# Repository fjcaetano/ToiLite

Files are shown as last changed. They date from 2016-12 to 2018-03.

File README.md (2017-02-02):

ToiLite
=====

A night light that lights up your toilette when you enter your restroom. Inspired by [IllumiBowl](https://illumibowl.com/).

### Partlist:
- 1 ATTiny85
- 1 RGB LED
- 1 LDR Sensor
- 1 PIR Sensor
- 1 Push button
- 1 Timpot (10k)
- 2 100R Resistor
- 2 150R Resistor
- 2 N-Type Mosfet (2N7000)
- 1 L78L33 Voltage Regulator
- 1 0.1µ Capacitor
- 1 0.33µ Capacitor

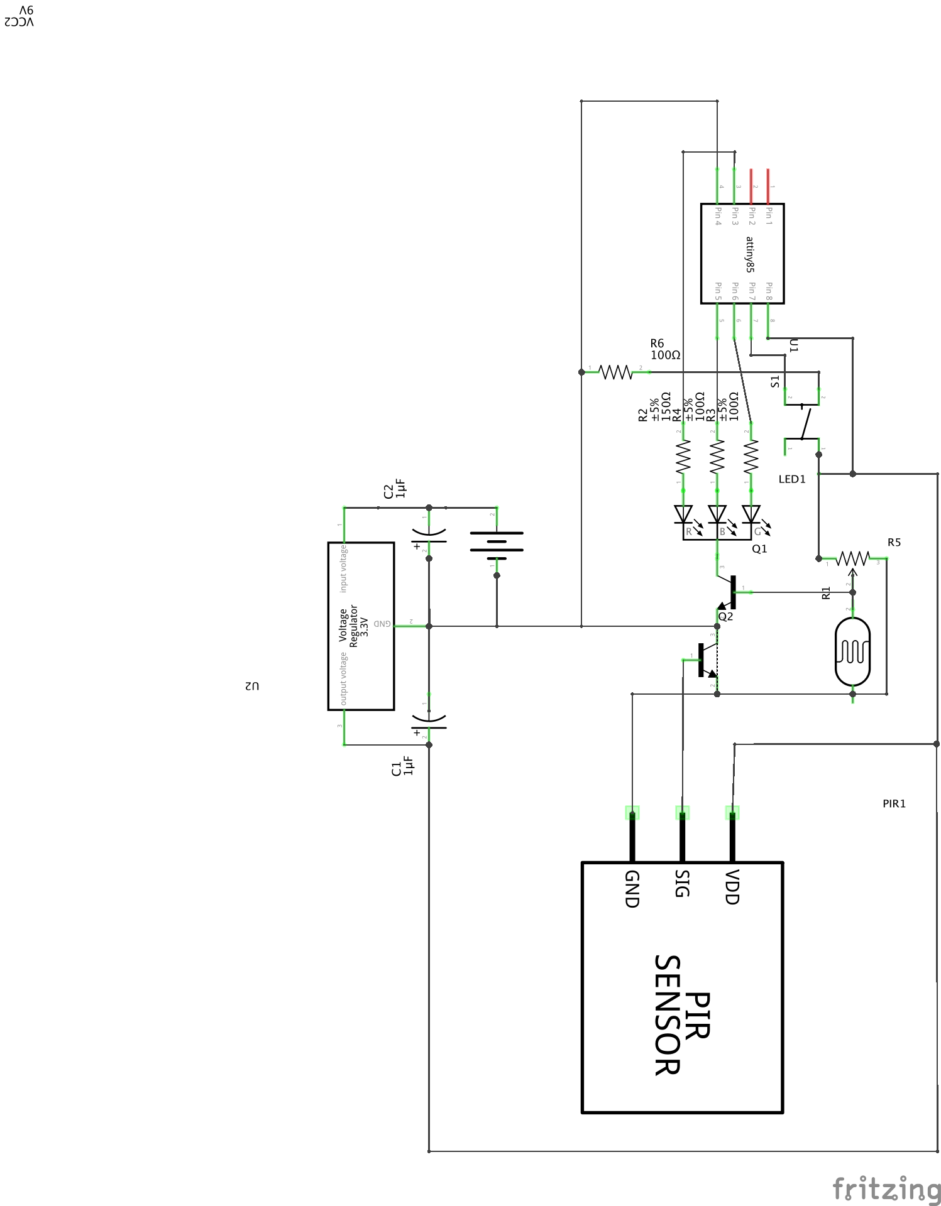
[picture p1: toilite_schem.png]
Schematics


The schematics and prototyping are using an ATTiny85 as microcontroller for the final product, but it can be easily exchanged for an Arduino board for tests.

### Perfboard

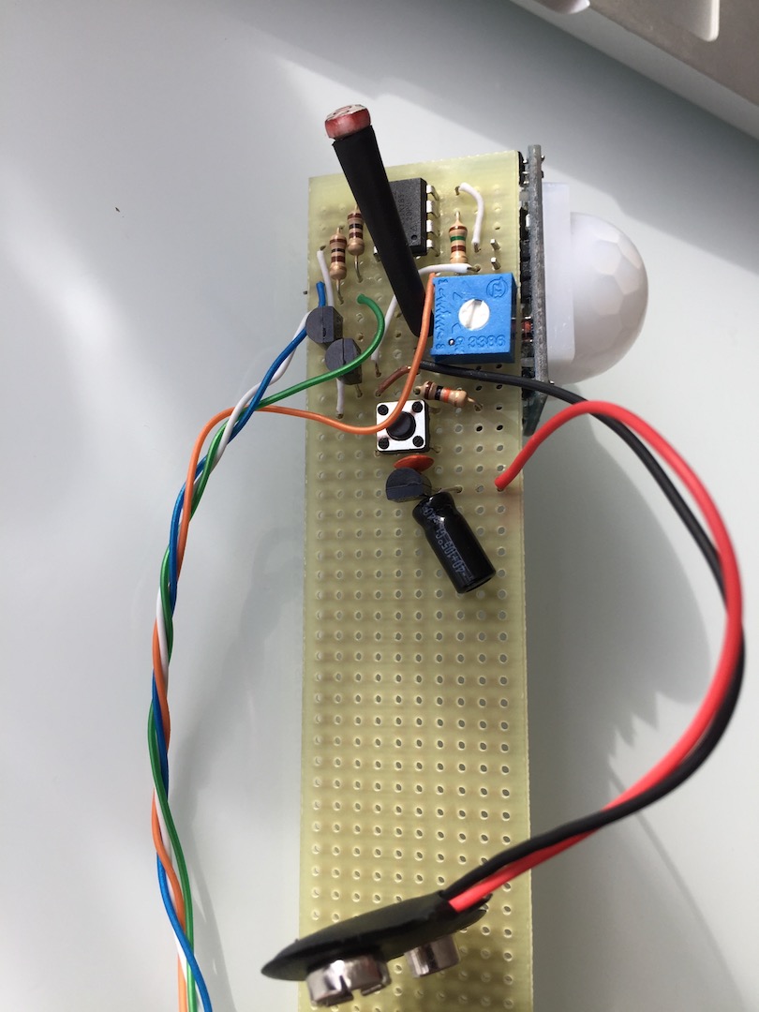
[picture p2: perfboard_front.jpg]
Perfboard front

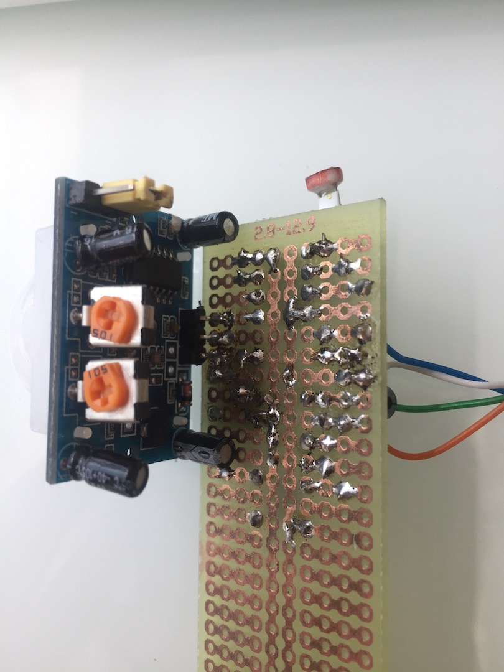
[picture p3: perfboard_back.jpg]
Perfboard back


### TODO
- [x] Hook up the PIR
- [x] Wire it up in a perfboard
- [x] Power source
- [ ] Make a housing for the product
- [ ] Install on a toilette

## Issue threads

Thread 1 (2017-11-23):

Spending too much battery

fjcaetano, 2017-11-23:
The processor doesn't need to be on until the PIR triggers it.

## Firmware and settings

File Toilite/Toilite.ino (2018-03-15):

/*
  ToiLite Controller

  Author: Flavio Caetano
*/

#include <EEPROM.h>

#define RED_PIN PB4 // PIN 3
#define GREEN_PIN PB1 // PIN 6
#define BLUE_PIN PB0 // PIN 5

#define BUTTON PB2 // PIN 7

typedef struct RGB {
  byte r;
  byte g;
  byte b;
};

RGB rgb(int h);
void setColorFromAngle(int angle);
void button_pressed();
void loop_colors(int startAngle);

int currentAngle;
volatile bool shouldStopLooping = false;

int main(void) {
  init();
  initVariant();

  pinMode(RED_PIN, OUTPUT);
  pinMode(GREEN_PIN, OUTPUT);
  pinMode(BLUE_PIN, OUTPUT);

  pinMode(BUTTON, INPUT_PULLUP);
  pinMode(A3, INPUT);

  randomSeed(analogRead(A3));

  // FOR ATTINY85
  GIMSK |= (1 << PCIE);    // turns on pin change interrupts
  PCMSK |= (1 << PCINT2);    // turn on interrupts on pins PB2
  sei();                 // enables interrupts

  int addr0 = EEPROM.read(0);
  int addr1 = EEPROM.read(1);

  currentAngle = (addr0 + (addr1 << 8));

  if (currentAngle != 0) {
    setColorFromAngle(currentAngle);
    shouldStopLooping = true;
  }
  else {
    currentAngle = random(360);
  }

  while (true) {
    loop_colors(currentAngle);
  }
}

ISR(PCINT0_vect) {
  if (digitalRead(BUTTON) == HIGH) return;
  
  if (EEPROM.read(0) == 0) {
    EEPROM.write(0, currentAngle % 256);
    EEPROM.write(1, currentAngle >> 8);

    shouldStopLooping = true;
  }
  else {
    // Clears EEPROM
    EEPROM.write(0, 0);
    EEPROM.write(1, 0);

    shouldStopLooping = false;
  }
}

void loop_colors(int startAngle) {
  for (currentAngle = startAngle; currentAngle < 360; currentAngle++) {
    if (shouldStopLooping) {
      return;
    }

    setColorFromAngle(currentAngle);

    delay(100);
  }

  currentAngle = 0;
}

void setColorFromAngle(int angle)
{
  RGB color = rgb(angle);
  analogWrite(RED_PIN, color.r);
  analogWrite(GREEN_PIN, color.g);
  analogWrite(BLUE_PIN, color.b);
}


RGB rgb(int h)
{
  int angle = (h >= 360 ? 0 : h);
  float sector = float(angle) / 60; // Sector
  int i = floor(sector);
  float f = sector - i; // Factorial part of h

  float q = (1 - f);

  switch (i) {
    case 0:
      return {0xff, int(f * 0xff), 0};

    case 1:
      return {int(q * 0xff), 0xff, 0};

    case 2:
      return {0, 0xff, int(f * 0xff)};

    case 3:
      return {0, int(q * 0xff), 0xff};

    case 4:
      return {int(f * 0xff), 0, 0xff};

    default:
      return {0xff, 0, int(q * 0xff)};
  }
}

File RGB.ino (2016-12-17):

/*
Adafruit Arduino - Lesson 3. RGB LED
*/

typedef struct RGB {
  byte r;
  byte g;
  byte b;
};

RGB rgb(int h);
void setColor(RGB rgb);

const int redPin = 4; // PIN 3
const int bluePin = 0; // PIN 5
const int greenPin = 1; // PIN 6

const int BUTTON = 2; // PIN 7
int buttonPreviousRead = LOW;
int isFixed = LOW;

RGB color;

//int POT = A0;
//int LDR = A1;

void setup()
{
//  Serial.begin(9600);

  pinMode(redPin, OUTPUT);
  pinMode(greenPin, OUTPUT);
  pinMode(bluePin, OUTPUT);

  pinMode(BUTTON, INPUT);
//  pinMode(POT, INPUT);
//  pinMode(LDR, INPUT);
}

void loop()
{
  for (int i = 0; i < 3600; i++) {
    int button = digitalRead(BUTTON);
//    int ldr = analogRead(LDR);
//    int pot = analogRead(POT);

    if (button == HIGH && buttonPreviousRead != HIGH) {
      isFixed = !isFixed;
    }

    buttonPreviousRead = button;

//    if (ldr < pot) {
      if (!isFixed) {
        color = rgb(i/10);
      }
      
      setColor(color);
//    }
//    else {
//      setColor({0, 0, 0});
//    }

    delay(10);
  }
}

void setColor(RGB rgb)
{
  analogWrite(redPin, rgb.r);
  analogWrite(greenPin, rgb.g);
  analogWrite(bluePin, rgb.b);
}


RGB rgb(int h)
{
  int angle = (h >= 360 ? 0 : h);
  float sector = float(angle) / 60; // Sector
  int i = floor(sector);
  float f = sector - i; // Factorial part of h

  float q = (1 - f);

  switch (i) {
    case 0:
      return {0xff, int(f * 0xff), 0};

    case 1:
      return {int(q * 0xff), 0xff, 0};

    case 2:
      return {0, 0xff, int(f * 0xff)};

    case 3:
      return {0, int(q * 0xff), 0xff};

    case 4:
      return {int(f * 0xff), 0, 0xff};

    default:
      return {0xff, 0, int(q * 0xff)};
  }
}

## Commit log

2016-12-17 PIR wired up
    [toilite.fzz]
2017-02-02 Power source
    [toilite.fzz]
2017-02-02 Fixing schematics
    [toilite.fzz]
2018-02-06 Fixing schematics rats nest
    [toilite.fzz]
2018-02-22 Storing selected color on EEPROM
    fix #3
    [Toilite.ino]
2018-02-22 Starting at a random color
    fix #2
    [Toilite.ino]
2018-03-15 Fix: enhancements for ATTiny85
    [Toilite.ino]
